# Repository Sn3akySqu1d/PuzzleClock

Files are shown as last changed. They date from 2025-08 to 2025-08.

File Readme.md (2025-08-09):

PuzzleClock is an alarm clock that makes you actually get out of bed. It makes you solve a random puzzle or game to disable the alarm and uses an ultrasonic sensor to detect if you try to return to bed instead of getting up. It is easy to build with an arduino uno and a few modules. It uses a rotary encoder, joystick, 128x64 lcd display, rtc module, ultrasonic sensor and passive buzzer. It can be powered through usb 2.0 or via a 9v battery.

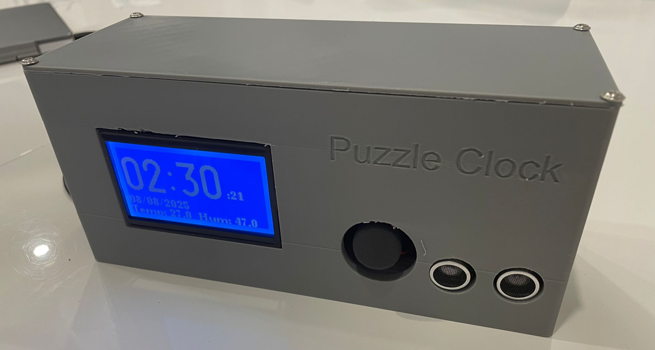
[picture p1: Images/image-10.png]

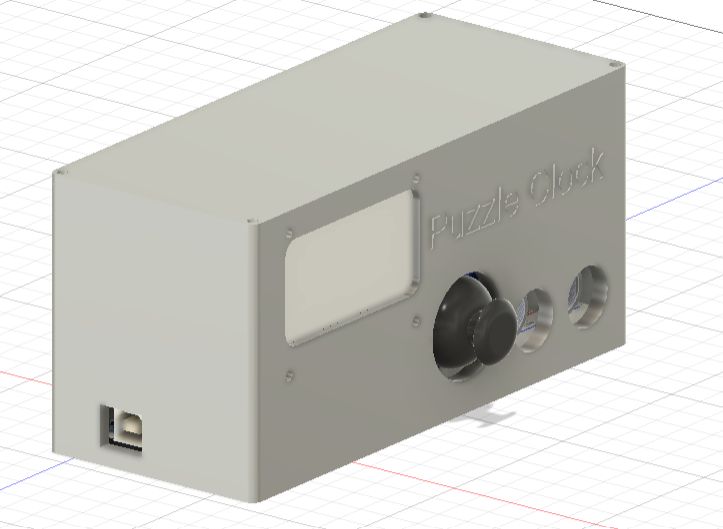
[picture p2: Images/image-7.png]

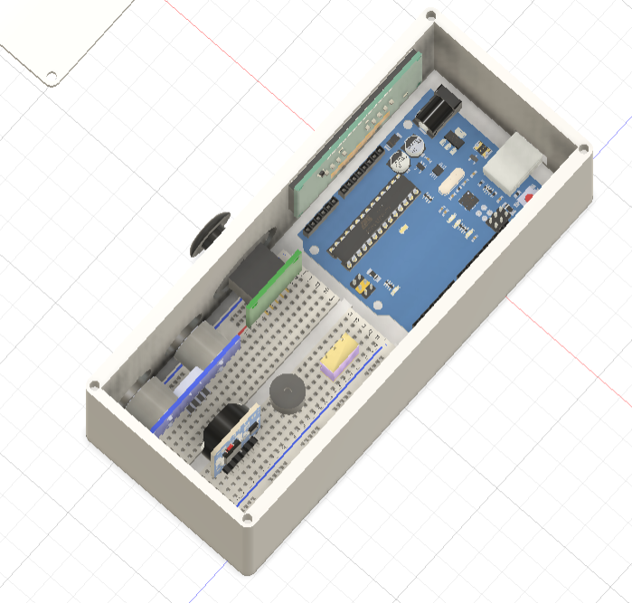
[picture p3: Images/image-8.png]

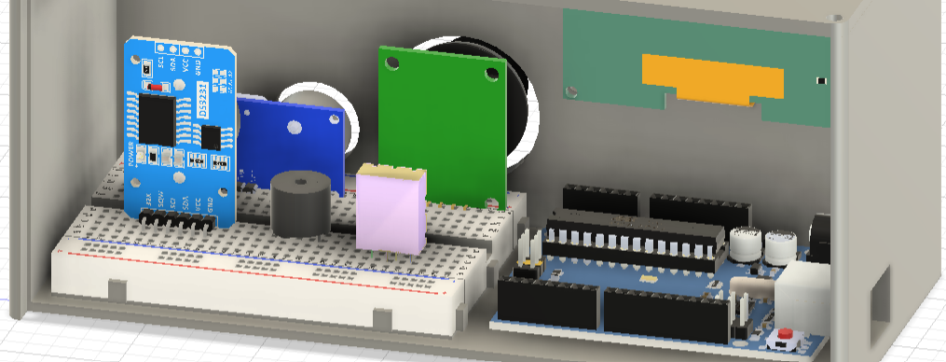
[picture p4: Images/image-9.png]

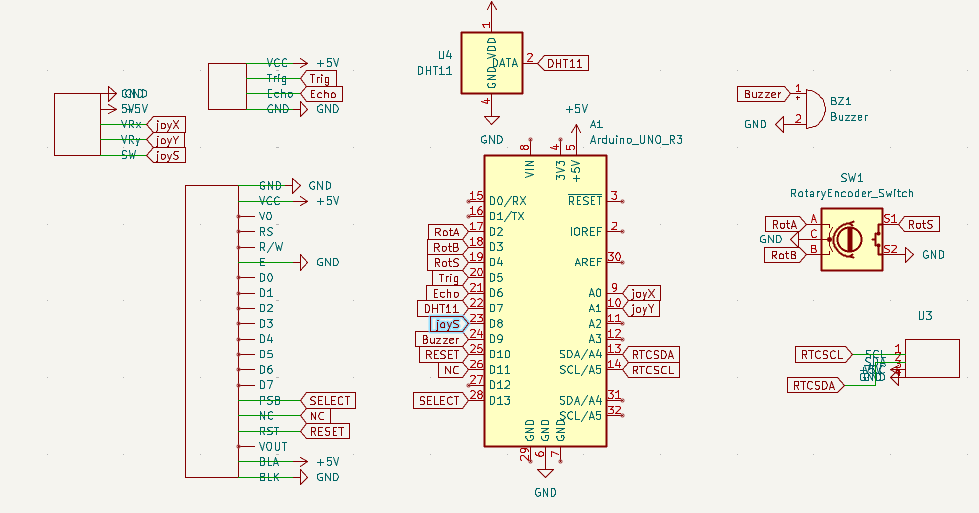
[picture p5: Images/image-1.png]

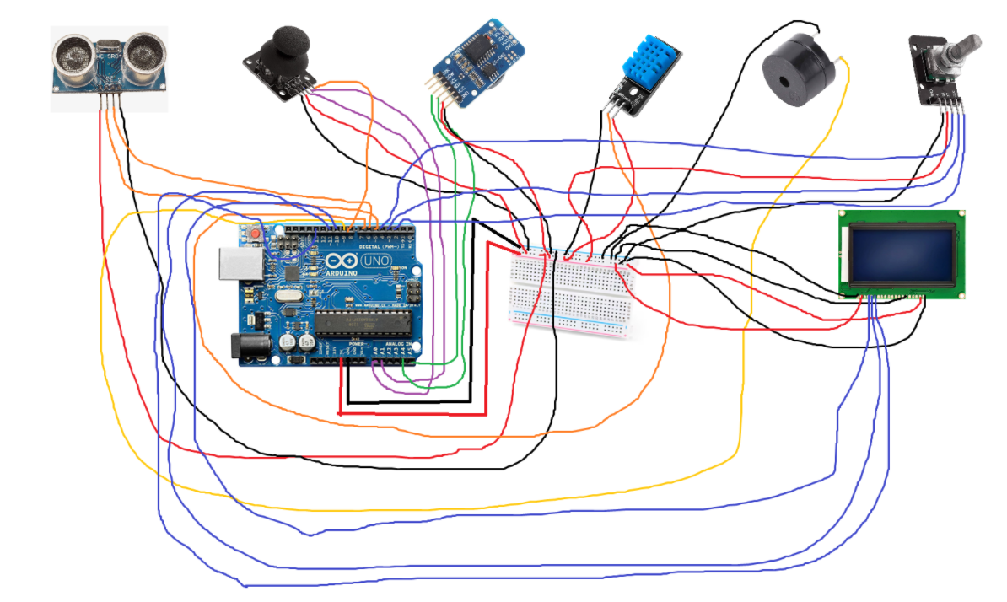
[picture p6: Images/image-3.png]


| Component | Link | Price (USD) |
|---|---|---|
| LCD Display | https://www.aliexpress.com/item/32815375122.html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 | 12.00 |
| Ultrasonic Sensor | Already have | 0.00 |
| Passive Buzzer | Already have | 0.00 |
| M3 screws | Already have | 0.00 |
| RTC Module | https://www.aliexpress.com/item/1005007143596890.html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 | 1.47 |
| Joystick Module | Already have | 0.00 |
| Arduino Uno | Already have | 0.00 |
| CR2032 Battery (for RTC, cheaper from local store as no shipping and dont need bulk) | https://www.sainsburys.co.uk/gol-ui/product/duracell-twin-coin-cell-battery--2032-3v | 6.60 |
| Case (3D Printed) | Printed with personal 3D printer | 0.00 |
Total: 20.07 usd

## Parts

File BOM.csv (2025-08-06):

lcd display | https://www.aliexpress.com/item/32815375122.html?src=google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 | 12
ultrasonic sensor | already have | 0
passive buzzer | already have | 0
m3 screws | already have | 0
rtc module | https://www.aliexpress.com/item/1005007143596890.html?utparam-url=scene%3Asearch%7Cquery_from%3A | 1.47
joystick module | already have | 0
arduino uno | alrady have | 0
CR2032 battery (for rtc) cheaper from local store than aliexpress with shipping and dont need bulk | https://www.sainsburys.co.uk/gol-ui/product/duracell-twin-coin-cell-battery--2032-3v | 6.6
case | 3d printed by my printer | 0

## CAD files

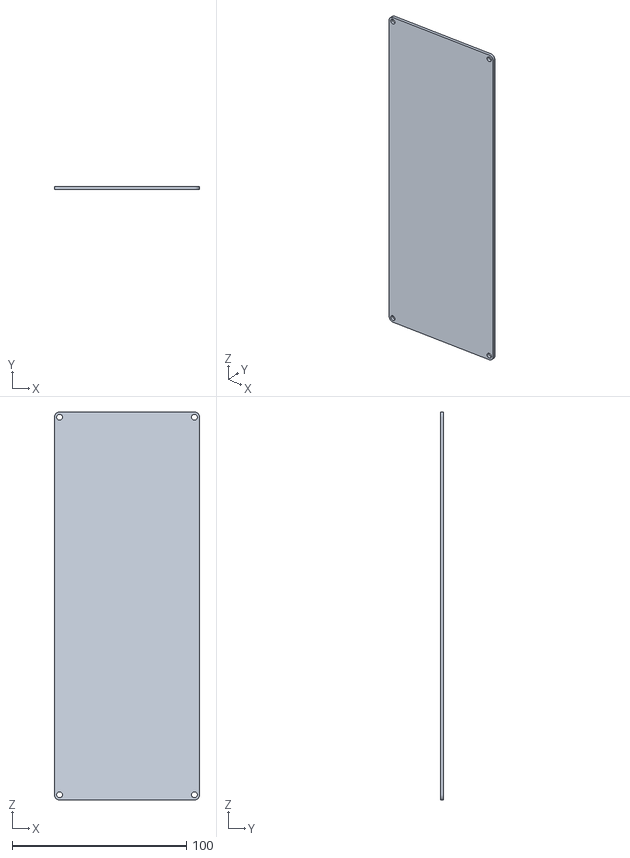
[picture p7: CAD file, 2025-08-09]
CAD/LidBigScreen.stl
83.4 x 2.00 x 222.6

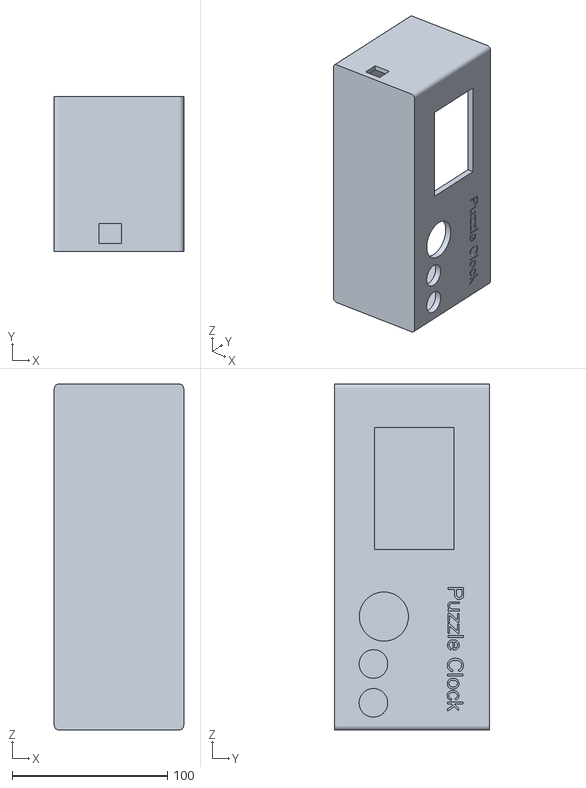
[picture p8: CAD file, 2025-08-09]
CAD/CaseBigScreen.stl
83.4 x 100.0 x 222.6

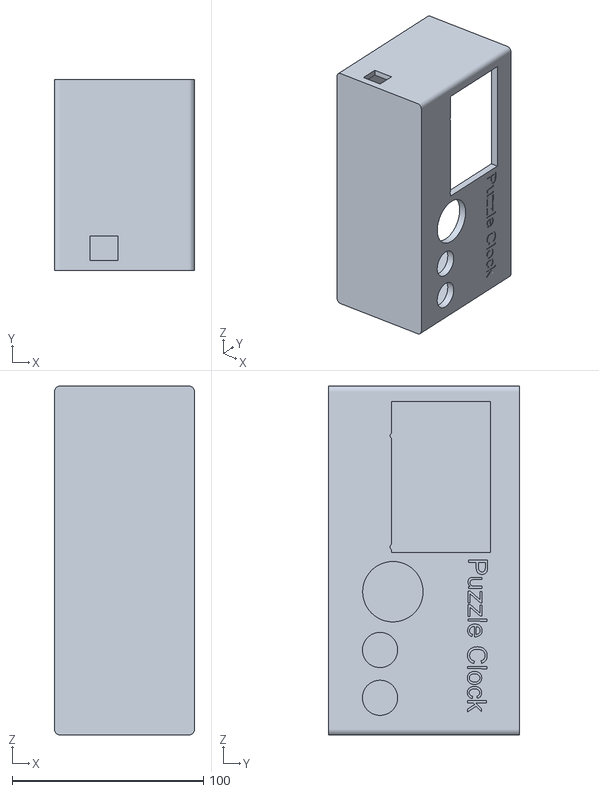
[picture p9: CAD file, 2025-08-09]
CAD/caseSmallerScreen.stl
73.4 x 100.0 x 182.6

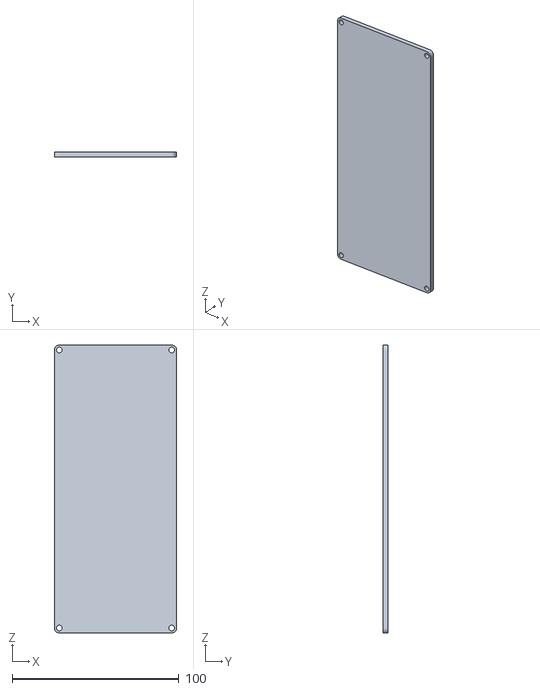
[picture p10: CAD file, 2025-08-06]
CAD/smallerLid.stl
73.3 x 3.00 x 172.6

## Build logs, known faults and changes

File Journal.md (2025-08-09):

---
title: "PuzzleClock"
author: "SneakySquid"
description: "PuzleClock is an alarm clock that makes you solve a puzzle to disable it"
created_at: "2024-03-20"
---

Total Design time: ~14 hours
Total Build time ~3 hours

# Day 1 (30/7) ~4 hours

Today I researched the best moduels to use. I settled on common inexpensive moduels that most people would have around to make this an easy project for others to build, with the exception of the large lcd screen. I decided to use lcd instead of oled as it is a lot cheaper for such a large screen. I decided to use an arduino uno as the microcontroller as it is the most common and most people would have one lying around. I refined the idea of the project and came up with some puzzles/games for the clock: maths question susing random numbers, a maze game, a snake clone and a game where you have to dodge a projected block. I have a joystick module lying around that I can incorporate into the design. I also decided to include an ultrasonic sensor to detect if the user tries to cheat and return to bed within a certain amount of time of disabling the alarm in which case the alarm is reenabled. Next, I created custom symbols for the components I would be using using the datasheets and wired everything up to create the schematic
  
I then created the case in fusion 360, after a few iterations going for this slanted design with cutouts for the components. I also engraved th ename of the project into the top left of the case. I will print the back of the case seperately to the rest of the case so its easy to access the inside of the clock once printed. I experimented with a few different designs at first but thought that this more ergonomic slanted case would look the best and is most convenient as it would be easily visble when laying down.
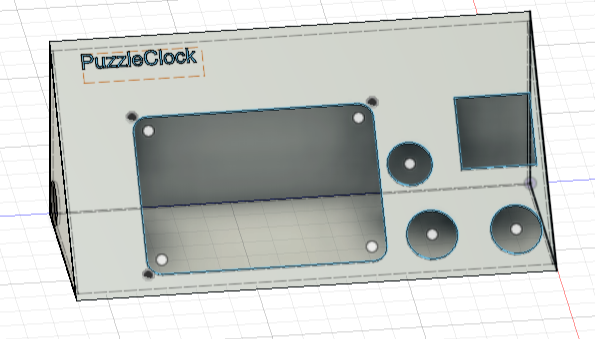
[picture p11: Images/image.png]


# Day 2 (31/7) ~6 hours

Today I wrote the arduino sketch for the project which was the most time consuming and difficult part. I need to wait for the lcd display to arrive to be able to test everything properly but I used some random arduino tutorials for different modules to create this sketch which i think should work. I started with base code for each moduel then built out the lcd display logic. I organised all of the logic to read the different sensors and the different games/puzzles into different functions to keep the code modularised and readable for easy debugging on the physical hardware and added a bunch of serial prints and error checks so its easy to tell what went wrong when i test this on the physcial project. I implemented a I also spent a while finding models of electronic components to put into the CAD of the case, importing everything into blender. I  wasn't able to get a render of the clock as my laptop isnt powerful enough but got this which shows roughly where each component will go. due to some weird scaling issues it looks like some of the components dont fit properly or clip through the model but they will fit properly in real life. Peformance issues on my laptop also made blender very difficult to work with.
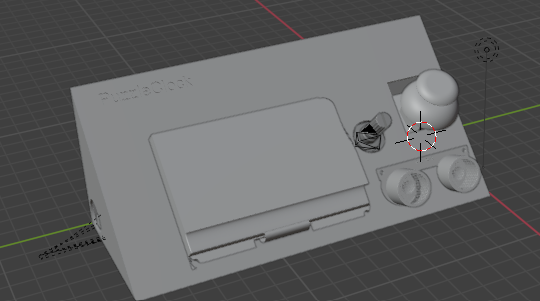
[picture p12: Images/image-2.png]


# Day 3 (4/8) ~ 1 hour
With the review feedback I created this wiring diagram and got a few more angles of the cad for the readme. I also filleted the edges of the case to make it less angular and more asthetically pleasing. Finally I updated the cad files in the repo.


# Day 4 (6/8) ~3 hours
I redesigned the entire case to make it more accessible and printable. I went for a more boxy design as is seen in some modern alarm clocks and i added a breadboard model to make it clear exactly how all of the components were going to be sitting in the case and then modelled cut outs in the case basd on that rather thna using abstract measurements. I also imported all of the components from grabcad into fusion360 so the project can be better visualised in colour and fixed all of the previous scaling issues. I also removed the rotary encoder as it is kind of redundant as we can use the joystick to navigate menus and updated the firmware to reflect this change.




# Build -----------------------------------------------------------------
# 7/8 ~3 hours
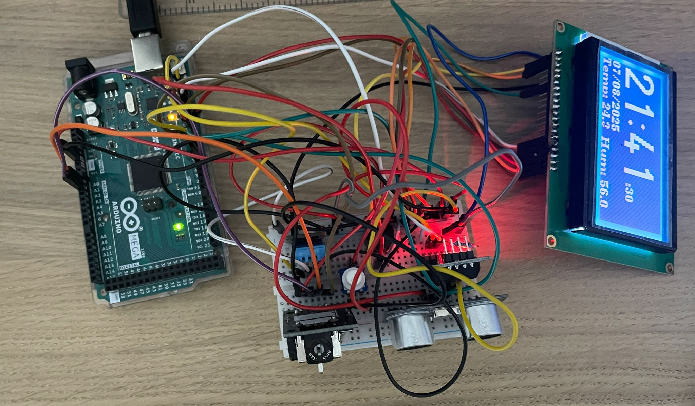
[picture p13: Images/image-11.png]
Firstly I tested each component induvidually on a breadboard to make sure they were working. I soldered header pins to the LCD display and it took me a while to get the display to work as there aren't many tutorials online for this specific model. After a while I realised that there were seperate backlight throughholes on the right edge of the board and that the actual backlight pins on the main section actually dont do anything. . The firmware worked pretty well but I had to switch from using an arduino uno to an arduino mega as the uno doesnt have enough ram to run the whole program but the mega does. In the future i think ill swap this for an esp32 as that has enough ram and is smaller so will save space in the case. I had to make the case bigger to fit the mega. Additionally, the pcb on the displayw as larger than that on the 3d model so I had to make the case slightly taller and deeper so that it doesnt knock into the joystick pcb.
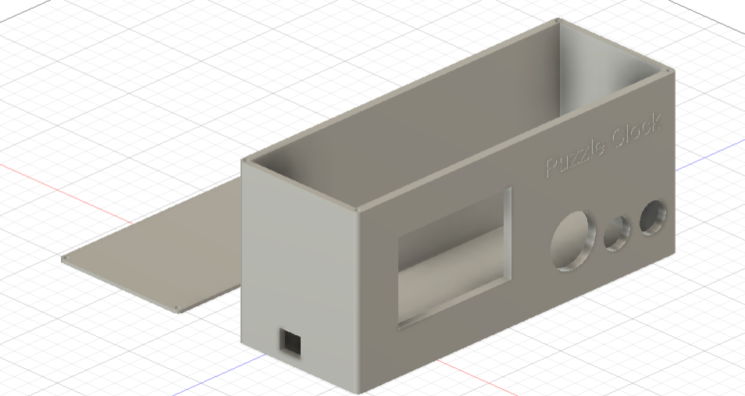
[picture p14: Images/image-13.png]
  
 I then printed the case, fixed in the lcd screen and screwed the lid to the case with the m3 screws, had to rewire a few times whiel putting everything in the case and retested the firmware to complete the physical build. I also updated the images in the repo and the CAD files, although also kept the old design as i think most 128 x64 lcs modules are the smaller variant so would be compatible with the old cad. In the future  I might swap out the mega with an esp32 to save space in the case aswell as that has enough dynamic memory for the sketch (uno doesnt).
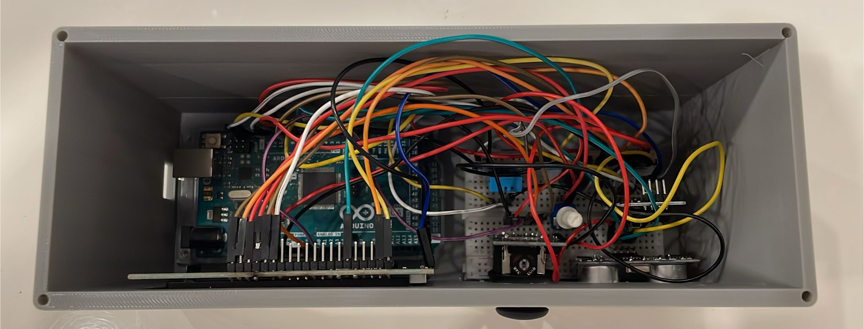
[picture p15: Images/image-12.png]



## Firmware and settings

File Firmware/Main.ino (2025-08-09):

#include <Wire.h>
#include <U8g2lib.h>
#include <RTClib.h>
#include <DHT.h>

U8G2_ST7920_128X64_F_SW_SPI display(U8G2_R2, 13, 11, 10);

#define DHTPIN 7
#define DHTTYPE DHT11
DHT dht(DHTPIN, DHTTYPE);

RTC_DS3231 rtc;
DateTime now;

#define JOY_X A0
#define JOY_Y A1
#define JOY_SW 8
int xVal, yVal;
bool swState, buttonPressed = false;
unsigned long lastButtonTime = 0;
const unsigned long debounceDelay = 200;

#define BUZZER_PIN 9

#define ULTRASONIC_TRIG 6
#define ULTRASONIC_ECHO 5
long lastAwayTime = 0;
bool userAway = false;
const unsigned long awayTimeout = 60000; // 1 minute after alarm to watch for return

// --- Alarm ---
int alarmHour = 22, alarmMinute = 9;
bool alarmActive = false;
bool inAlarmTimeSetting = false;
bool settingHours = true;

enum MainMenuOptions { MENU_CLOCK, MENU_ALARM, MENU_GAMES };
int mainMenuIndex = 0;
const int mainMenuItems = 3;

enum AlarmMenuOptions { ALARM_SET_TIME, ALARM_BACK };
int alarmMenuIndex = 0;
const int alarmMenuItems = 2;

enum GamesMenuOptions { GAME_MATH, GAME_DODGE, GAME_MAZE, GAME_BACK };
int gamesMenuIndex = 0;
const int gamesMenuItems = 4;

bool inMainMenu = false;
bool inAlarmMenu = false;
bool inGamesMenu = false;

float temp = 0, humidity = 0;

enum AlarmGame { NONE, MATH, DODGE, MAZE};
AlarmGame currentAlarmGame = NONE;
bool gameCompleted = false;

int mathNum1, mathNum2, mathAnswer, mathUserAnswer, mathStage = 0;

const int maxDodgeBlocks = 3;
int dodgePlayerX = 7;
int dodgeObstacleX[maxDodgeBlocks];
int dodgeObstacleY[maxDodgeBlocks];
int dodgeScore = 0;
unsigned long dodgeLastMove = 0;
const int dodgeScoreToWin = 15;

const int mazeWidth = 7;
const int mazeHeight = 7;
const char mazeMap[mazeHeight][mazeWidth+1] = {
  "#######",
  "#     #",
  "# ### #",
  "# #   #",
  "# # ###",
  "#     #",
  "#######"
};
int mazePlayerX = 1, mazePlayerY = 1;
int mazeGoalX = 5, mazeGoalY = 5;

void setup() {
  Serial.begin(9600);
  dht.begin();
  rtc.begin();
  if (rtc.lostPower()) rtc.adjust(DateTime(F(__DATE__), F(__TIME__)));

  display.begin();
  display.setFont(u8g2_font_ncenB08_tr);

  pinMode(JOY_SW, INPUT_PULLUP);
  pinMode(BUZZER_PIN, OUTPUT);

  pinMode(ULTRASONIC_TRIG, OUTPUT);
  pinMode(ULTRASONIC_ECHO, INPUT);

  randomSeed(analogRead(A2));
}

void loop() {
  now = rtc.now();

  float h = dht.readHumidity();
  float t = dht.readTemperature();

  // Only update if valid readings
  if (!isnan(h) && !isnan(t)) {
    humidity = h;
    temp = t;
  }

  readJoystick();

  if (alarmActive && currentAlarmGame == NONE) {
    currentAlarmGame = static_cast<AlarmGame>(random(1, 4));
    resetGameVars(currentAlarmGame);
    gameCompleted = false;
    tone(BUZZER_PIN, 1000);
    lastAwayTime = millis();
    userAway = false;
  }

  if (alarmActive) {
    long dist = readUltrasonicDistance();
    if (!userAway && dist > 50) {
      userAway = true;
      lastAwayTime = millis();
    }
    if (userAway && dist < 30 && millis() - lastAwayTime < awayTimeout) {
      currentAlarmGame = NONE;
      alarmActive = false;
      noTone(BUZZER_PIN);
      delay(200);
      alarmActive = true;
      return;
    }
  }

  if (alarmActive && !gameCompleted) {
    playAlarmGame();
  } else if (currentAlarmGame != NONE && gameCompleted) {
    noTone(BUZZER_PIN);
    alarmActive = false;
    currentAlarmGame = NONE;
    inGamesMenu = false;
    inAlarmTimeSetting = false;
    inAlarmMenu = false;
    inMainMenu = true;
  } else {
    if (inMainMenu) drawMainMenu();
    else if (inAlarmMenu) drawAlarmMenu();
    else if (inGamesMenu) {
      if (currentAlarmGame != NONE) {
        playAlarmGame();
      } else {
        drawGamesMenu();
      }
    }
    else if (mainMenuIndex == MENU_CLOCK) drawClockScreen();
    else if (mainMenuIndex == MENU_ALARM) drawAlarmClockScreen();
    else if (mainMenuIndex == MENU_GAMES) {
      display.clearBuffer();
      display.drawStr(0, 12, "Press to open");
      display.drawStr(0, 28, "Games menu");
      display.sendBuffer();
    }
  }

  checkAlarm();

  delay(100);
}

long readUltrasonicDistance() {
  digitalWrite(ULTRASONIC_TRIG, LOW);
  delayMicroseconds(2);
  digitalWrite(ULTRASONIC_TRIG, HIGH);
  delayMicroseconds(10);
  digitalWrite(ULTRASONIC_TRIG, LOW);

  long duration = pulseIn(ULTRASONIC_ECHO, HIGH, 30000);
  long distanceCm = duration / 29 / 2;
  if (distanceCm == 0) distanceCm = 255;
  return distanceCm;
}

void readJoystick() {
  xVal = analogRead(JOY_X);
  yVal = analogRead(JOY_Y);
  swState = !digitalRead(JOY_SW);
  unsigned long nowMs = millis();

  if (swState && !buttonPressed && nowMs - lastButtonTime > debounceDelay) {
    lastButtonTime = nowMs;
    buttonPressed = true;

    if (alarmActive && !gameCompleted && currentAlarmGame != NONE) {
      return;
    }

    if (inAlarmTimeSetting) {
      if (settingHours) settingHours = false;
      else {
        inAlarmTimeSetting = false;
        inAlarmMenu = true;
      }
      return;
    }

    if (inGamesMenu) {
      if (gamesMenuIndex == GAME_BACK) {
        inGamesMenu = false;
        inMainMenu = true;
      } else {
        currentAlarmGame = static_cast<AlarmGame>(gamesMenuIndex + 1);
        resetGameVars(currentAlarmGame);
        gameCompleted = false;
      }
      return;
    }

    if (inAlarmMenu) {
      if (alarmMenuIndex == ALARM_SET_TIME) {
        inAlarmTimeSetting = true;
        settingHours = true;
      } else if (alarmMenuIndex == ALARM_BACK) {
        inAlarmMenu = false;
        inMainMenu = true;
      }
      return;
    }

    if (inMainMenu) {
      switch(mainMenuIndex) {
        case MENU_CLOCK: inMainMenu = false; break;
        case MENU_ALARM: inMainMenu = false; inAlarmMenu = true; break;
        case MENU_GAMES: inMainMenu = false; inGamesMenu = true; break;
      }
      return;
    }

    inMainMenu = true;
  }
  if (!swState) buttonPressed = false;

  if (nowMs - lastButtonTime > debounceDelay) {
    if (inMainMenu) {
      if (yVal > 700 && mainMenuIndex > 0) mainMenuIndex--;
      else if (yVal < 300 && mainMenuIndex < mainMenuItems - 1) mainMenuIndex++;
      lastButtonTime = nowMs;
    }
    else if (inAlarmMenu) {
      if (yVal > 700 && alarmMenuIndex > 0) alarmMenuIndex--;
      else if (yVal < 300 && alarmMenuIndex < alarmMenuItems - 1) alarmMenuIndex++;
      lastButtonTime = nowMs;
    }
    else if (inGamesMenu && currentAlarmGame == NONE) {
      if (yVal > 700 && gamesMenuIndex > 0) gamesMenuIndex--;
      else if (yVal < 300 && gamesMenuIndex < gamesMenuItems - 1) gamesMenuIndex++;
      lastButtonTime = nowMs;
    }

    if (inAlarmTimeSetting) {
      if (xVal > 700) {
        if (settingHours) alarmHour = (alarmHour + 1) % 24;
        else alarmMinute = (alarmMinute + 1) % 60;
        delay(200);
      }
      else if (xVal < 300) {
        if (settingHours) alarmHour = (alarmHour == 0) ? 23 : alarmHour - 1;
        else alarmMinute = (alarmMinute == 0) ? 59 : alarmMinute - 1;
        delay(200);
      }
    }
  }
}

void checkAlarm() {
  if (now.hour() == alarmHour && now.minute() == alarmMinute && now.second() == 0 && !alarmActive) {
    alarmActive = true;
    currentAlarmGame = NONE;
  }
  if (!alarmActive) {
    noTone(BUZZER_PIN);
  }
}

void drawMainMenu() {
  display.clearBuffer();
  display.drawStr(0, 10, mainMenuIndex == MENU_CLOCK ? "> Clock" : "  Clock");
  display.drawStr(0, 20, mainMenuIndex == MENU_ALARM ? "> Alarm" : "  Alarm");
  display.drawStr(0, 30, mainMenuIndex == MENU_GAMES ? "> Games" : "  Games");
  display.sendBuffer();
}

void drawAlarmMenu() {
  display.clearBuffer();
  display.drawStr(0, 10, "Alarm Menu");
  display.drawStr(0, 20, alarmMenuIndex == ALARM_SET_TIME ? "> Set Alarm Time" : "  Set Alarm Time");
  display.drawStr(0, 30, alarmMenuIndex == ALARM_BACK ? "> Back" : "  Back");
  display.sendBuffer();
}

void drawGamesMenu() {
  display.clearBuffer();
  display.drawStr(0, 10, gamesMenuIndex == GAME_MATH ? "> Math Game" : "  Math Game");
  display.drawStr(0, 20, gamesMenuIndex == GAME_DODGE ? "> Dodge Game" : "  Dodge Game");
  display.drawStr(0, 30, gamesMenuIndex == GAME_MAZE ? "> Maze Game" : "  Maze Game");
  display.drawStr(0, 50, gamesMenuIndex == GAME_BACK ? "> Back" : "  Back");
  display.sendBuffer();
}

void drawClockScreen() {
  display.clearBuffer();

  display.setFont(u8g2_font_logisoso32_tf);
  char timeStr[10];
  snprintf(timeStr, sizeof(timeStr), "%02d:%02d", now.hour(), now.minute());
  display.drawStr(0, 40, timeStr);

  display.setFont(u8g2_font_ncenB08_tr);
  char secondsStr[4];
  snprintf(secondsStr, sizeof(secondsStr), ":%02d", now.second());
  display.drawStr(95, 38, secondsStr);

  char dateStr[16];
  snprintf(dateStr, sizeof(dateStr), "%02d/%02d/%04d", now.day(), now.month(), now.year());
  display.drawStr(0, 54, dateStr);

  char tempStr[20];
  dtostrf(temp, 4, 1, tempStr);
  display.drawStr(0, 64, (String("Temp: ") + tempStr).c_str());

  char humStr[20];
  dtostrf(humidity, 4, 1, humStr);
  display.drawStr(64, 64, (String("Hum: ") + humStr).c_str());

  display.sendBuffer();
}

void drawAlarmClockScreen() {
  display.clearBuffer();
  display.drawStr(0, 12, "Alarm Clock");

  char alarmStr[20];
  snprintf(alarmStr, sizeof(alarmStr), "Alarm: %02d:%02d", alarmHour, alarmMinute);
  display.drawStr(0, 28, alarmStr);

  if (alarmActive) {
    display.drawStr(0, 44, "ALARM RINGING!");
    display.drawStr(0, 60, "Solve game to stop");
  } else if (inAlarmTimeSetting) {
    display.drawStr(0, 44, settingHours ? "Set HOUR" : "Set MIN");
    display.drawStr(0, 60, "Press to next");
  } else {
    display.drawStr(0, 44, alarmMenuIndex == ALARM_SET_TIME ? "> Set Alarm Time" : "  Set Alarm Time");
    display.drawStr(0, 60, alarmMenuIndex == ALARM_BACK ? "> Back" : "  Back");
  }

  display.sendBuffer();
}


void resetGameVars(AlarmGame game) {
  switch (game) {
    case MATH:
      mathNum1 = random(1, 10);
      mathNum2 = random(1, 10);
      mathAnswer = mathNum1 + mathNum2;
      mathUserAnswer = 0;
      mathStage = 0;
      break;

    case DODGE:
      dodgePlayerX = 7;
      dodgeScore = 0;
      dodgeLastMove = millis();
      for (int i = 0; i < maxDodgeBlocks; i++) {
        dodgeObstacleX[i] = random(0, 15);
        dodgeObstacleY[i] = random(-8, 0);
      }
      break;

    case MAZE:
      mazePlayerX = 1;
      mazePlayerY = 1;
      gameCompleted = false;
      break;

    default:
      break;
  }
}

void playAlarmGame() {
  switch (currentAlarmGame) {
    case MATH: playMathGame(); break;
    case DODGE: playDodgeGame(); break;
    case MAZE: playMazeGame(); break;
    default: break;
  }
}

void playMathGame() {
  display.clearBuffer();
  display.setFont(u8g2_font_ncenB08_tr);
  char buf[32];
  snprintf(buf, sizeof(buf), "Solve: %d + %d =", mathNum1, mathNum2);
  display.drawStr(0, 12, buf);

  snprintf(buf, sizeof(buf), "Ans: %d", mathUserAnswer);
  display.drawStr(0, 28, buf);
  display.drawStr(0, 44, "Press Btn to submit");

  display.sendBuffer();

  if (xVal > 700) {
    mathUserAnswer++;
    delay(150);
  } else if (xVal < 300 && mathUserAnswer > 0) {
    mathUserAnswer--;
    delay(150);
  }

  if (swState && !buttonPressed) {
    buttonPressed = true;
    if (mathUserAnswer == mathAnswer) {
      gameCompleted = true;
    }
  }
  if (!swState) buttonPressed = false;
}

void playDodgeGame() {
  display.clearBuffer();
  display.drawStr(0, 0, "Dodge blocks!");
  display.drawFrame(0, 12, 128, 48);

  unsigned long nowMs = millis();

  display.drawBox(dodgePlayerX * 8, 56, 8, 8);

  for (int i = 0; i < maxDodgeBlocks; i++) {
    display.drawBox(dodgeObstacleX[i] * 8, dodgeObstacleY[i] * 8 + 12, 8, 8);
  }

  display.setCursor(0, 63);
  display.print("Score: ");
  display.print(dodgeScore);

  display.sendBuffer();

  if (xVal > 700 && dodgePlayerX < 15) {
    dodgePlayerX++;
    delay(150);
  } else if (xVal < 300 && dodgePlayerX > 0) {
    dodgePlayerX--;
    delay(150);
  }

  if (nowMs - dodgeLastMove > 400) {
    dodgeLastMove = nowMs;
    for (int i = 0; i < maxDodgeBlocks; i++) {
      dodgeObstacleY[i]++;
      if (dodgeObstacleY[i] > 5) {
        if (dodgeObstacleX[i] == dodgePlayerX) {
          // Hit! Fail game & stop alarm
          gameCompleted = false;
          alarmActive = false;
          noTone(BUZZER_PIN);
          return;
        } else {
          dodgeScore++;
          dodgeObstacleX[i] = random(0, 15);
          dodgeObstacleY[i] = 0;
          if (dodgeScore >= dodgeScoreToWin) {
            gameCompleted = true;
            return;
          }
        }
      }
    }
  }

  if (swState && !buttonPressed) {
    buttonPressed = true;
  }
  if (!swState) buttonPressed = false;
}

void playMazeGame() {
  display.clearBuffer();

  for (int y = 0; y < mazeHeight; y++) {
    for (int x = 0; x < mazeWidth; x++) {
      int px = x * 8;
      int py = 10 + y * 8;

      if (mazeMap[y][x] == '#') display.drawBox(px, py, 8, 8);
      else display.drawFrame(px, py, 8, 8);

      if (x == mazePlayerX && y == mazePlayerY) display.drawStr(px + 2, py + 7, "P");
      if (x == mazeGoalX && y == mazeGoalY) display.drawStr(px + 2, py + 7, "G");
    }
  }
  display.sendBuffer();

  if (xVal > 700 && canMove(mazePlayerX + 1, mazePlayerY)) {
    mazePlayerX++;
    delay(300);
  } else if (xVal < 300 && canMove(mazePlayerX - 1, mazePlayerY)) {
    mazePlayerX--;
    delay(300);
  } else if (yVal > 700 && canMove(mazePlayerX, mazePlayerY - 1)) {
    mazePlayerY--;
    delay(300);
  } else if (yVal < 300 && canMove(mazePlayerX, mazePlayerY + 1)) {
    mazePlayerY++;
    delay(300);
  }

  if (mazePlayerX == mazeGoalX && mazePlayerY == mazeGoalY) {
    gameCompleted = true;
  }
}

bool canMove(int x, int y) {
  if (x < 0 || x >= mazeWidth || y < 0 || y >= mazeHeight) return false;
  return mazeMap[y][x] != '#';
}

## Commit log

2025-08-04 wiring diagram + cad update
    [casev2.f3d, projectv2.step]
2025-08-06 updated case
    [Case.stl, Lid.stl, case.obj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]
2025-08-09 build completed
    [Case.stl, CaseBigScreen.stl, LidBigScreen.stl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]
